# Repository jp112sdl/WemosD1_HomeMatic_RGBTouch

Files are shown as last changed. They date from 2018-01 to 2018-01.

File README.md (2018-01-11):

# WemosD1 HomeMatic RGBTouch Controller
TFT/Touchscreen-Fernbedienung für HomeMatic RGB Controller und/oder UP-Dimmer<br>
Die Steuerung erfolgt direkt über die Seriennummer des HomeMatic-Geräts.<br>
Es ist **keine** Zusatzsoftware auf der CCU2 notwendig.

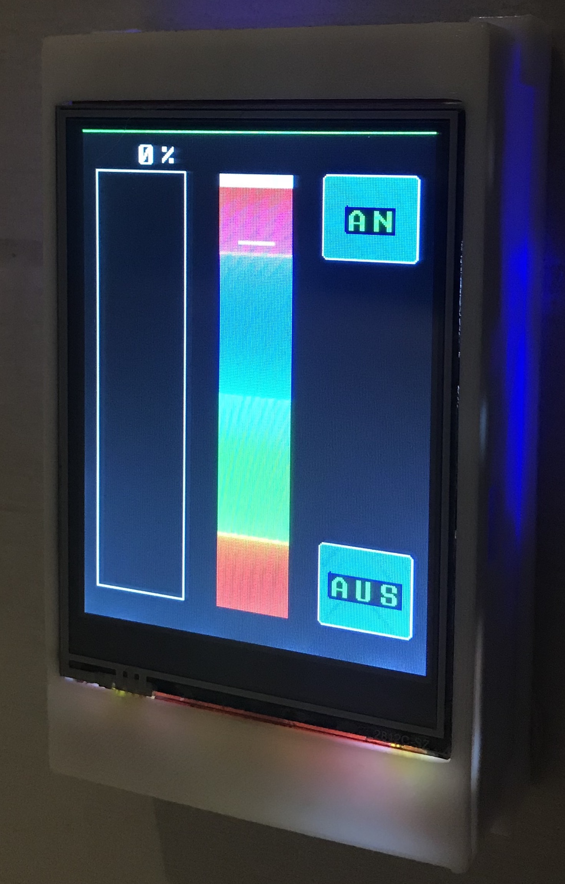
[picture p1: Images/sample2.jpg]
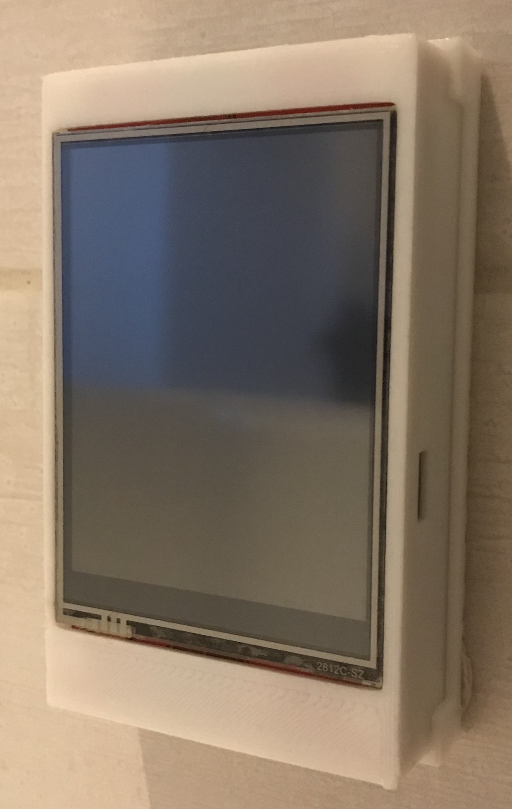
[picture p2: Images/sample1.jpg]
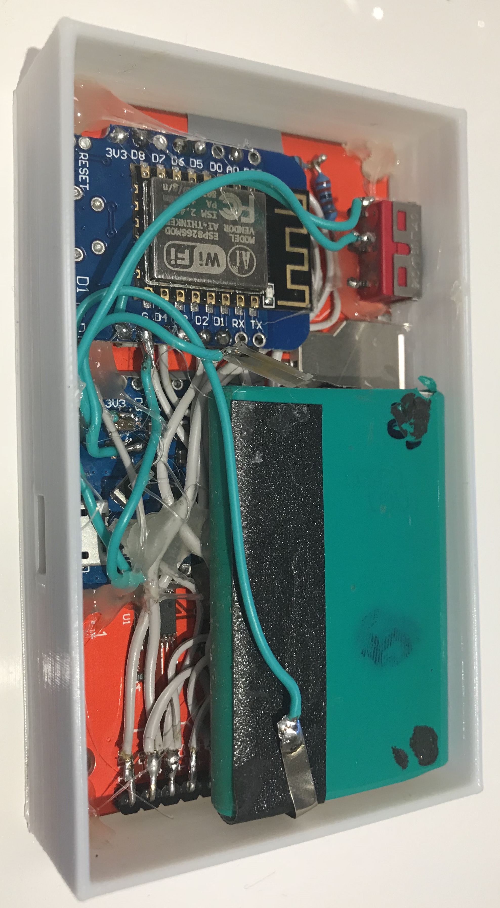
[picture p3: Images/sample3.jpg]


### Bauteile:
- 1x Wemos D1 mini
- 1x TFT Touchscreen, ILI9341 kompatibel und mit SPI Anschluss (z.B. [hier](https://www.ebay.de/itm/172726994916))
- 1x beliebiger Taster
- 1x Widerstand, irgendwas zwischen 1k...10k Ohm (dient nur als Pullup)
- _bei Akkubetrieb empfiehlt sich zusätzlich noch ein Wemos BatteryShield und ein 3.7V LiPo Akku_
  - _auf die Stromversorgung wird hier nicht weiter eingegangen_
  
### Verdrahtung:
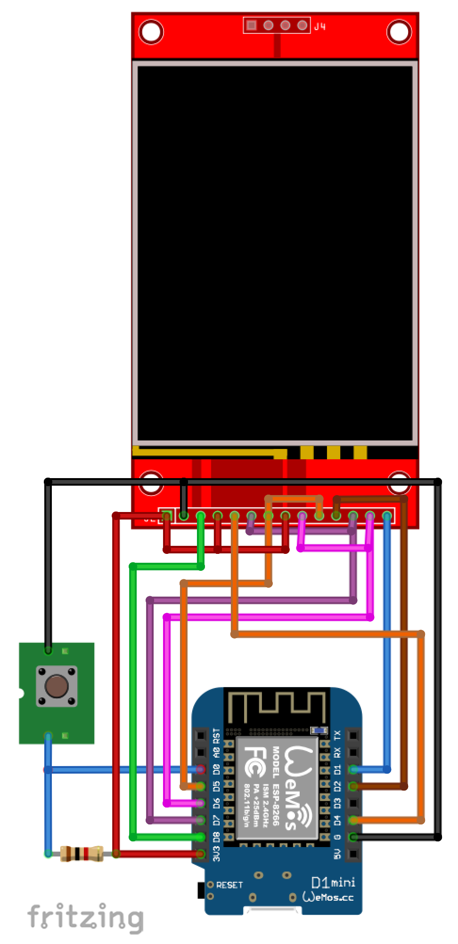
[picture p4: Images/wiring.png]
<br>
Die Fritzing-Datei kann auch [heruntergeladen](https://github.com/jp112sdl/WemosD1_HomeMatic_RGBTouch/blob/master/Images/Schaltplan.fzz) werden.

### Inbetriebnahme:
1. Touchscreen berühren und dabei das Gerät einschalten
2. AP-Modus wird gestartet<br>
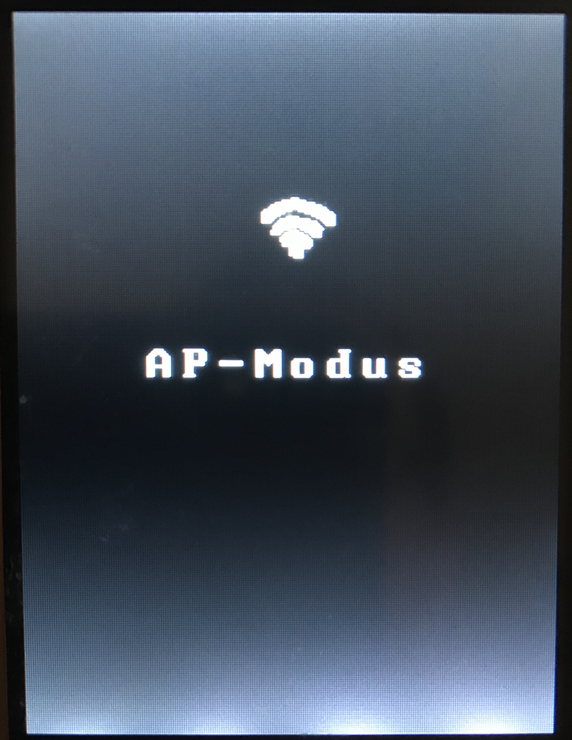
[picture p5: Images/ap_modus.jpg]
<br>
3. Nach neuen WLANs am Notebook suchen und mit dem WLAN WemosD1-xx:xx:xx:xx:xx:xx verbinden
4. Konfigurationsseite öffnen: http://192.168.4.1 und dort die Daten entsprechend eingeben, anschließend speichern.

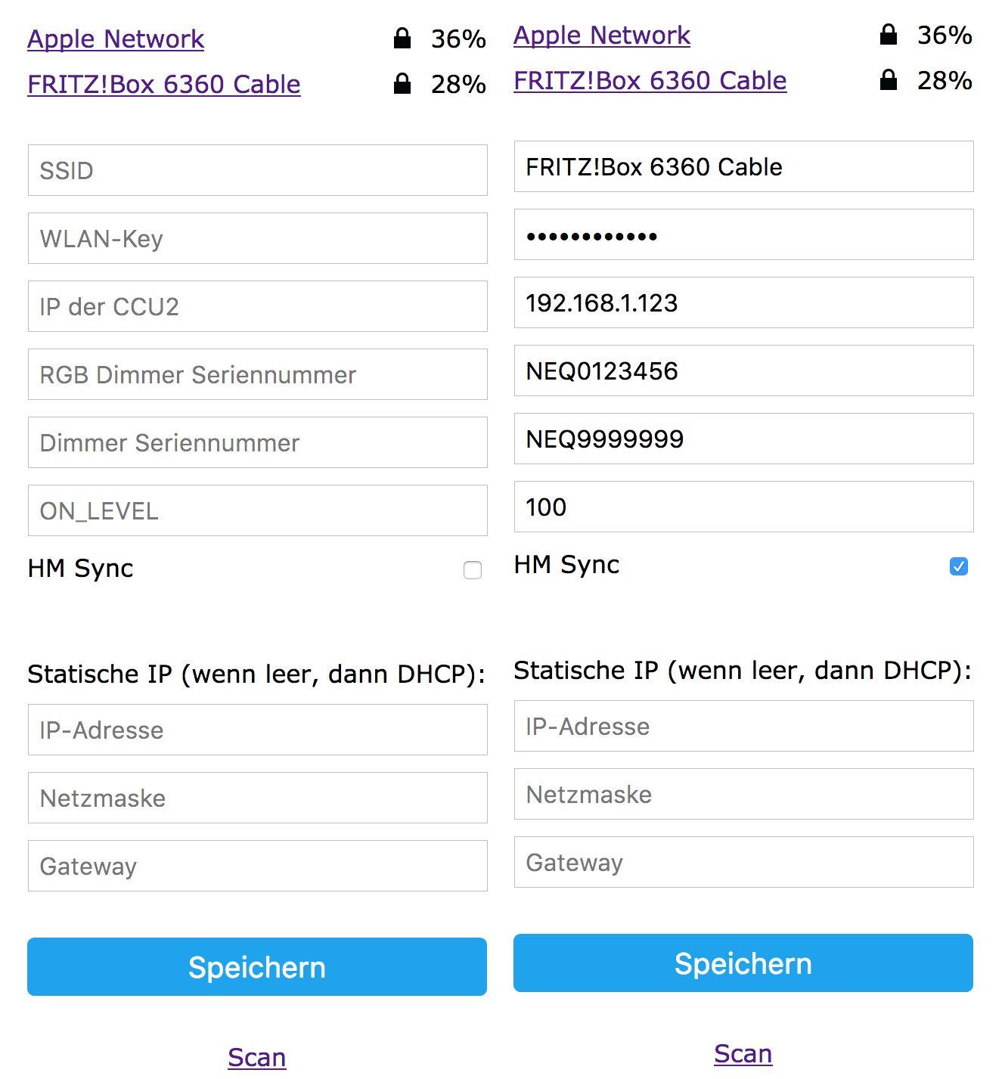
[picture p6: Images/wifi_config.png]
<br>

**Erklärung der Felder:**
- SSID / WLAN-Key, IP der CCU2, RGB Dimmer Seriennummer und UP Dimmer Seriennummer sind wohl selbsterklärend
- **es ist auch möglich nur EINEN von beiden Dimmern zu benutzen! Es ist dann das Feld (Seriennummer) des ungenutzten Dimmertyps leer zu lassen.**
- ON_LEVEL: Die Buttons AN und AUS am rechten Bildschirmrand dienen dem schnellen Ein- und Ausschalten des UP-Dimmers. Bei "AUS" wird 0% angefahren, bei "EIN" der im ON_LEVEL definierte Wert.
- HM Sync: wenn aktiviert, wird alle 30 Sekunden die CCU2 abgefragt, ob die angezeigten Werte noch dem IST-Zustand entsprechen. Wenn nicht (weil bspw. jemand per Schalter den Dimmer betätigt hat) wird der neue/aktuelle Wert am TFT angezeigt.

### Gehäuse:
Mein verwendetes Gehäuse gibt es als [.stl](https://github.com/jp112sdl/WemosD1_HomeMatic_RGBTouch/blob/master/Images/HomeMatic%20RGB%20Dimmer.stl) und als [.obj](https://github.com/jp112sdl/WemosD1_HomeMatic_RGBTouch/blob/master/Images/HomeMaticRGBDimmerOBJ.zip) im komprimierten zip-File.

### Kalibrierung des Touchscreens:
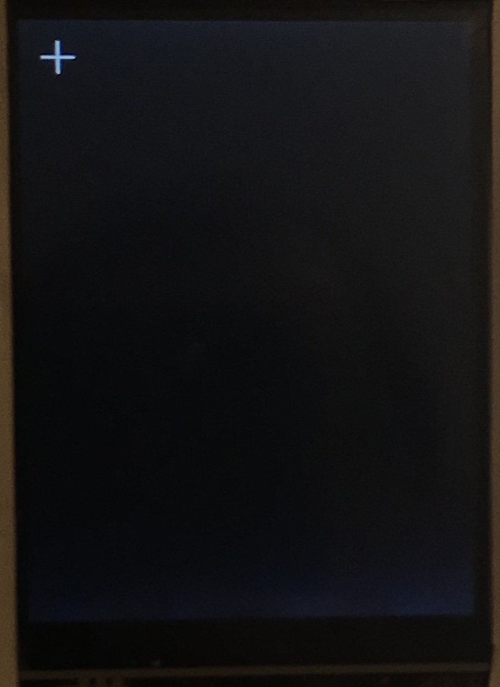
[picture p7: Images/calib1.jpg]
<br>
- Bei gedrücktem Taster den Wemos einschalten.<br>
- Es erscheint ein Fadenkreuz in der Ecke oben links
- Das Fadenkreuz (am besten mit einem Stift) antippen
- Es erscheint ein Fadenkreuz in der Ecke unten rechts
- Das Fadenkreuz (am besten mit einem Stift) antippen

Die Kalibrierung ist nun beendet. Die Kalibrierungsdaten werden gespeichert und sind dauerhaft gespeichert.
Der Vorgang kann jederzeit wiederholt werden

Wer "Danke" sagen möchte (in Form einer kleinen Spende), kann gern hier klicken:

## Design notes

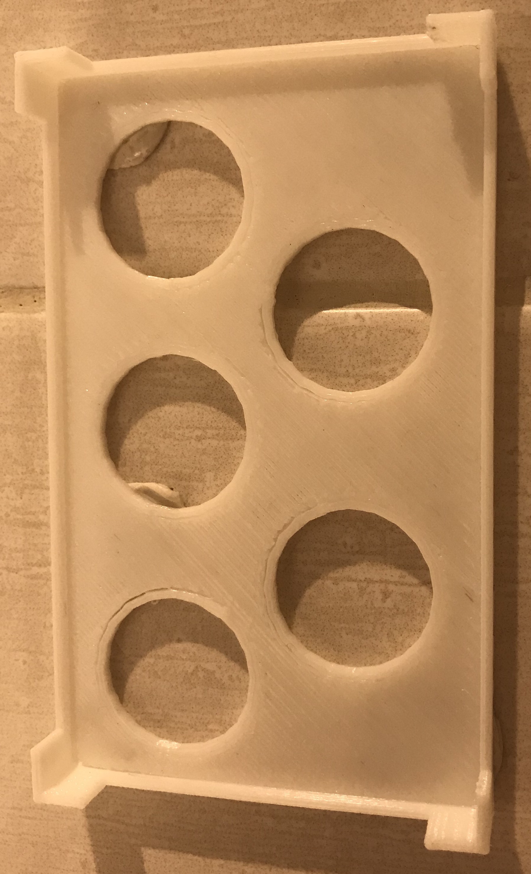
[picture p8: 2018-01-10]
Images/sample4.jpg

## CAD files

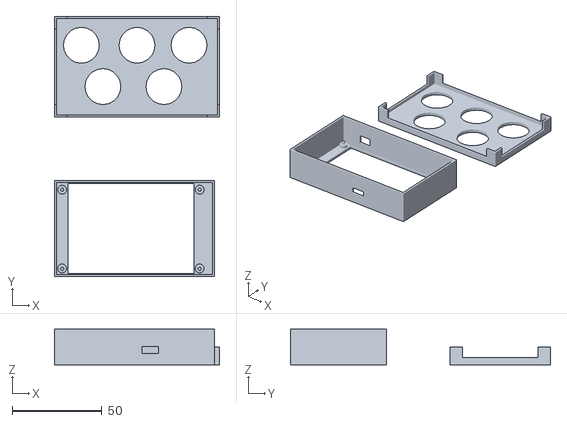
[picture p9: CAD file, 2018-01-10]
Images/HomeMatic RGB Dimmer.stl
92.2 x 145.2 x 20.0

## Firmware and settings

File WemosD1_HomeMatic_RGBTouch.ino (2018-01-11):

#include <ESP8266WiFi.h>
#include <ESP8266HTTPClient.h>
#include <Arduino.h>
#include <FS.h>
#include <ArduinoOTA.h>
#include <UTFT.h>
#include <SPI.h>
#include <XPT2046.h>
#include <ArduinoJson.h>
#include <WiFiManager.h>

#define ESP_SPI_FREQ 16000000L

#define IPSIZE                16
#define VARIABLESIZE         255
#define ConfigPortalTimeout  180  //Timeout (Sekunden) des AP-Modus
#define HTTPTimeOut         1500  //Timeout (Millisekunden) für http requests
#define SYNCINTERVAL         30   //Sekunden
#define CalibrationSwitch    D0   //Taster zum Starten der Touchscreen-Kalibrierung

const String configJsonFile         = "tc.json";
const String calibJsonFile          = "cal.json";

extern unsigned  wifiicon32[1024];
extern unsigned  RGBhorz_halb[27948];

UTFT myGLCD (ILI9341_S5P, 15, 5, 2);
XPT2046 myTouch(/*cs=*/ 4, /*irq=*/ 5);

HTTPClient http;

char Hostname[] = "WEMOS-HM-RGBTOUCH";

struct wemosnetconfig_t {
  char ip[IPSIZE]      = "0.0.0.0";
  char netmask[IPSIZE] = "0.0.0.0";
  char gw[IPSIZE]      = "0.0.0.0";
} WemosNetConfig;

struct hmconfig_t {
  char ccuIP[IPSIZE]   = "";
  char RGB_Dimmer_Serial[VARIABLESIZE] = "";
  char UP_Dimmer_Serial[VARIABLESIZE] =  "";
  bool enableSync = false;
  byte OnLevel = 100;
} HomeMaticConfig;

struct touchcalibration_t {
  int P1 = 244;
  int P2 = 1735;
  int P3 = 1728;
  int P4 = 264;
} TouchCalibration;

bool isDimTouching = false;
bool isRGBTouching = false;
int posX = 20; // Start x
int posY = 10; // Start y
int posEndX = 274;
int posEndY = 65;
int percentX = 312;
int percentY = 8;

int buttonWidth = 50;
int buttonHeight = 60;
int buttonOffX = 20;
int buttonOffY = 170;
int buttonOnX = 244;
int buttonOnY = 170;

int wifiIconX = 210;
int wifiIconY = 108;
int RGBstartX = 20;
int RGBstartY = 100;
int RGBheight = 274;
int RGBwidth = 25;
int RGBbarCount = 2;

boolean isFrameSet = false; // Wert wird true wenn Frame erstmalig geschrieben - nicht manuell anpassen!
extern uint8_t BigFont[];
int intAusgabe;
unsigned long lastSyncMillis = 0;

//bool Debug = false;
bool startWifiManager = false;
bool wm_shouldSaveConfig = false;
bool isRGBavailable = true;
bool isDIMavailable = true;
String lastLEVELValue = "";
String lastCOLORValue = "";


void setup() {
  pinMode(LED_BUILTIN, OUTPUT);
  pinMode(CalibrationSwitch, INPUT);
  SPI.setFrequency(ESP_SPI_FREQ);
  myGLCD.InitLCD(LANDSCAPE);
  myGLCD.clrScr();
  myGLCD.setFont(BigFont);
  myGLCD.setColor(255, 255, 255);
  Serial.begin(115200);

  myTouch.begin((uint16_t)myGLCD.getDisplayYSize(), (uint16_t)myGLCD.getDisplayXSize());

  if (digitalRead(CalibrationSwitch) == LOW) {
    calibrate();
  } else {
    loadCalibrationConfig();
  }
  
  myTouch.setRotation(myTouch.ROT270);
  myTouch.setCalibration(TouchCalibration.P1, TouchCalibration.P2, TouchCalibration.P3, TouchCalibration.P4);

  if (!loadSystemConfig()) startWifiManager = true;
  if (myTouch.isTouching()) startWifiManager = true;

  isRGBavailable = (String(HomeMaticConfig.RGB_Dimmer_Serial) != "");
  isDIMavailable = (String(HomeMaticConfig.UP_Dimmer_Serial) != "");

  if (doWifiConnect() == false) {
    myGLCD.clrScr();
    myGLCD.setFont(BigFont);
    myGLCD.setColor(255, 255, 255);
    myGLCD.print("  Fehler bei ", 175, 00, 90);
    myGLCD.print("WLAN-Verbindung", 155, 00, 90);
    delay(2000);
    ESP.restart();
  }
  else {
    startOTAhandling();
    myGLCD.clrScr();
    slider_init();
    if (isDIMavailable) on_off_button_init();
  }
}

void loop() {
  ArduinoOTA.handle();
  if (lastSyncMillis > millis())
    lastSyncMillis = millis();

  if (WiFi.status() == WL_CONNECTED) {
    slider_read();
    if (millis() - lastSyncMillis > SYNCINTERVAL * 1000) {
      Serial.println("SYNC HM");
      lastSyncMillis = millis();
      slider_init();
    }

    yield();

  } else ESP.restart();
}

void slider_init() {
  myGLCD.setColor(255, 255, 255);
  myGLCD.drawRect (posX, posY, posX + posEndX, posY + posEndY);
  bool CCUerror = false;
  if (!isRGBavailable) {
    memcpy(HomeMaticConfig.RGB_Dimmer_Serial, HomeMaticConfig.UP_Dimmer_Serial, VARIABLESIZE);
    Serial.println("slider_init(): RGB Dimmer NOT available");
  }
  //aktuellen LEVEL holen und anzeigen
  String currentLEVELValue = getStateFromCCU(HomeMaticConfig.RGB_Dimmer_Serial, "1.LEVEL");
  if (currentLEVELValue != lastLEVELValue) {
    lastLEVELValue = currentLEVELValue;
    CCUerror = !drawCurrentDimLevel(currentLEVELValue);
  }

  if (isRGBavailable) {
    String currentCOLORValue = getStateFromCCU(HomeMaticConfig.RGB_Dimmer_Serial, "2.COLOR");
    if (currentCOLORValue != "error") {
      if (currentCOLORValue != lastCOLORValue) {
        lastCOLORValue = currentCOLORValue;
        myGLCD.setColor(255, 255, 255);

        int knobPosX = (((float)currentCOLORValue.toInt() / 200.0) + ((float)RGBstartX / (float)RGBheight)) * (float)RGBheight;
        draw_knob(knobPosX);
        yield();
      }
    } else {
      CCUerror = true;
    }
  }

  if (CCUerror) {
    myGLCD.clrScr();
    myGLCD.setFont(BigFont);
    myGLCD.setColor(255, 255, 255);
    myGLCD.print("  Fehler bei ", 175, 00, 90);
    myGLCD.print("CCU2-Verbindung", 155, 00, 90);
    myGLCD.setColor(255, 0, 0);
    myGLCD.drawLine(319, 0, 319, 240);
    myTouch.powerDown();
  } else {
    myGLCD.setColor(0, 255, 0);
    myGLCD.drawLine(319, 0, 319, 240);
  }
}

void on_off_button_init() {
  //AN / AUS BUTTONS
  myGLCD.setColor(0, 0, 255);
  myGLCD.fillRoundRect (buttonOffX, buttonOffY, buttonOffX + buttonWidth, buttonOffY + buttonHeight);
  myGLCD.setColor(255, 255, 255);
  myGLCD.drawRoundRect (buttonOffX, buttonOffY, buttonOffX + buttonWidth, buttonOffY + buttonHeight);

  myGLCD.setColor(0, 0, 255);
  myGLCD.fillRoundRect (buttonOnX, buttonOnY, buttonOnX + buttonWidth, buttonOnY + buttonHeight);
  myGLCD.setColor(255, 255, 255);
  myGLCD.drawRoundRect (buttonOnX, buttonOnY, buttonOnX + buttonWidth, buttonOnY + buttonHeight);

  myGLCD.setColor(0, 255, 0);
  myGLCD.print("AUS",   52, 177, 90);
  myGLCD.print("AN",   275, 185, 90);
  //
}

// Slider auslesen und Werte zurückgeben
int slider_read() {
  float tPosX;
  float tPosY;
  float tAusgabe;
  if (myTouch.isTouching()) {
    //Serial.println("Touch detected.");
    uint16_t x, y;
    int xCumul = 0;
    int yCumul = 0;
    for (int touchCount = 0; touchCount < 100; touchCount++) {
      myTouch.getPosition(x, y);
      xCumul += x;
      yCumul += y;
    }
    tPosX = xCumul / 100;
    tPosY = yCumul / 100;
    //Serial.println("tPosX = " + String(tPosX) + "; tPosY = " + String(tPosY));

    if (isDIMavailable) {
      if ((tPosY > buttonOffY) && (tPosY < buttonOffY + buttonHeight)) {
        if ((tPosX > buttonOffX) && (tPosX < buttonOffX + buttonWidth)) {
          waitForIt(buttonOffX, buttonOffY, buttonOffX + buttonWidth, buttonOffY + buttonHeight);
          Serial.println("OFF BUTTON pressed.");
          setStateCCU(HomeMaticConfig.UP_Dimmer_Serial, "1.LEVEL", "0.0");
          if (!isRGBavailable) drawCurrentDimLevel("0");
        }
      }

      if ((tPosY > buttonOnY) && (tPosY < buttonOnY + buttonHeight)) {
        if ((tPosX > buttonOnX) && (tPosX < buttonOnX + buttonWidth)) {
          waitForIt(buttonOnX, buttonOnY, buttonOnX + buttonWidth, buttonOnY + buttonHeight);
          Serial.println("ON BUTTON pressed. ON_LEVEL = " + String(HomeMaticConfig.OnLevel));
          setStateCCU(HomeMaticConfig.UP_Dimmer_Serial, "1.LEVEL", String((float)(HomeMaticConfig.OnLevel / 100.0)));
          if (!isRGBavailable) drawCurrentDimLevel(String((float)(HomeMaticConfig.OnLevel / 100.0)));
        }
      }
    }

    if (tPosX >= posX && tPosX <= posX + posEndX && tPosY >= posY && tPosY <= posY + posEndY) {
      isDimTouching = true;
      draw_used_unused(tPosX, tPosY);
      tAusgabe = ((tPosX - posY) / posEndX) * 100;
      intAusgabe = (int)tAusgabe - 3;
      String displayPercent = "   " + String(intAusgabe);
      displayPercent = displayPercent.substring(displayPercent.length() - 3) + "%";
      myGLCD.setColor(255, 255, 255);
      myGLCD.print(displayPercent, percentX, percentY, 90);
    }
    //RGB
    if (isRGBavailable && tPosX >= RGBstartX && tPosX <= RGBstartX + RGBheight && tPosY >= RGBstartY && tPosY <= RGBstartY +  (RGBwidth * RGBbarCount)) {
      draw_knob(tPosX);
      isRGBTouching = true;
      tAusgabe = ((tPosX - RGBstartX) / RGBheight) * 200;
      intAusgabe = (int) tAusgabe;
    }
  }
  else {
    if (isDimTouching) {
      if (intAusgabe < 4) intAusgabe = 0;
      String val = "00" + String(intAusgabe);
      val = "0." + val.substring(val.length() - 2);
      Serial.println("Setze CCU Wert " + String(HomeMaticConfig.RGB_Dimmer_Serial) + "1.LEVEL = " + val);
      setStateCCU(HomeMaticConfig.RGB_Dimmer_Serial, "1.LEVEL", val);
      isDimTouching = false;
    }
    //RGB
    if (isRGBTouching) {
      Serial.println("Setze CCU Wert " + String(HomeMaticConfig.RGB_Dimmer_Serial) + "2.COLOR = " + String(intAusgabe));
      setStateCCU(HomeMaticConfig.RGB_Dimmer_Serial, "2.COLOR", String(intAusgabe));
      isRGBTouching = false;
    }
  }
}

// Draw a red frame while a button is touched
void waitForIt(int x1, int y1, int x2, int y2) {
  myGLCD.setColor(255, 0, 0);
  myGLCD.drawRoundRect (x1, y1, x2, y2);
  while (myTouch.isTouching()) yield(); //loop
  myGLCD.setColor(255, 255, 255);
  myGLCD.drawRoundRect (x1, y1, x2, y2);
}

// Schieberegler
void draw_knob(int tPosX) {
  word tColor;
  for (int barCount = 0; barCount < RGBbarCount; barCount++)
    myGLCD.drawBitmap (RGBstartX, RGBstartY + (RGBwidth * barCount), RGBheight, RGBwidth, RGBhorz_halb, 1);
  tColor = myGLCD.getColor();
  myGLCD.setColor(255, 255, 255);

  myGLCD.fillRect(tPosX - 1, RGBstartY + ( (RGBwidth * RGBbarCount) / 2) - ( (RGBwidth * RGBbarCount) / 4), tPosX, RGBstartY + ( (RGBwidth * RGBbarCount) / 2) + ( (RGBwidth * RGBbarCount) / 4));
  // myGLCD.drawLine(posX, RGBstartY + ( (RGBwidth * RGBbarCount) / 2), tPosX, RGBstartY + ( (RGBwidth * RGBbarCount) / 2));

  myGLCD.setColor(tColor);
}

void draw_used_unused(int tPosX, int tPosY) {
  //Serial.println("draw_used_unused("+String(tPosX)+","+String(tPosY)+")");
  const word usedColor = VGA_WHITE; // Farbe f. genutzen Anteil
  const word unusedColor = VGA_BLACK; // Farbe f. ungenutzen Anteil
  word tColor;
  tColor = myGLCD.getColor();
  myGLCD.setColor(usedColor);
  for (int tPosY = posY; tPosY <= posY + posEndY; tPosY++) myGLCD.drawLine(posX, tPosY, tPosX, tPosY);
  myGLCD.setColor(tColor);
  myGLCD.setColor(unusedColor);
  for (int tPosY = posY; tPosY <= posY + posEndY; tPosY++) myGLCD.drawLine(tPosX, tPosY, posX + posEndX, tPosY);
  myGLCD.setColor(255, 255, 255);
  myGLCD.drawRect (posX, posY, posX + posEndX, posY + posEndY);
  myGLCD.setColor(tColor);
}

String IpAddress2String(const IPAddress& ipAddress) {
  return String(ipAddress[0]) + String(".") + \
         String(ipAddress[1]) + String(".") + \
         String(ipAddress[2]) + String(".") + \
         String(ipAddress[3]);
}

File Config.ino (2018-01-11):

#define JSONCONFIG_IP                     "ip"
#define JSONCONFIG_NETMASK                "netmask"
#define JSONCONFIG_GW                     "gw"
#define JSONCONFIG_CCUIP                  "ccuip"
#define JSONCONFIG_RGBDIMMER              "rgbdimser"
#define JSONCONFIG_UPDIMMER               "updimmer"
#define JSONCONFIG_ENABLESYNC             "sync"
#define JSONCONFIG_ONLEVEL                "onlevel"

bool loadSystemConfig() {
  Serial.println(F("loadSystemConfig mounting FS..."));
  if (SPIFFS.begin()) {
    Serial.println(F("loadSystemConfig mounted file system"));
    if (SPIFFS.exists("/" + configJsonFile)) {
      Serial.println(F("loadSystemConfig reading config file"));
      File configFile = SPIFFS.open("/" + configJsonFile, "r");
      if (configFile) {
        Serial.println(F("loadSystemConfig opened config file"));
        size_t size = configFile.size();
        std::unique_ptr<char[]> buf(new char[size]);

        configFile.readBytes(buf.get(), size);
        DynamicJsonBuffer jsonBuffer;
        JsonObject& json = jsonBuffer.parseObject(buf.get());
        Serial.println("Content of JSON Config-File: /" + configJsonFile);
        json.printTo(Serial);
        Serial.println();
        if (json.success()) {
          Serial.println("\nJSON OK");
          ((json[JSONCONFIG_IP]).as<String>()).toCharArray(WemosNetConfig.ip, IPSIZE);
          ((json[JSONCONFIG_NETMASK]).as<String>()).toCharArray(WemosNetConfig.netmask, IPSIZE);
          ((json[JSONCONFIG_GW]).as<String>()).toCharArray(WemosNetConfig.gw, IPSIZE);
          ((json[JSONCONFIG_CCUIP]).as<String>()).toCharArray(HomeMaticConfig.ccuIP, IPSIZE);
          ((json[JSONCONFIG_RGBDIMMER]).as<String>()).toCharArray(HomeMaticConfig.RGB_Dimmer_Serial, VARIABLESIZE);
          ((json[JSONCONFIG_UPDIMMER]).as<String>()).toCharArray(HomeMaticConfig.UP_Dimmer_Serial, VARIABLESIZE);
          HomeMaticConfig.enableSync = json[JSONCONFIG_ENABLESYNC];
          HomeMaticConfig.OnLevel = json[JSONCONFIG_ONLEVEL];
        } else {
          Serial.println(F("\nloadSystemConfig ERROR loading config"));
        }
      }
      return true;
    } else {
      Serial.println("/" + configJsonFile + " not found.");
      return false;
    }
    SPIFFS.end();
  } else {
    Serial.println(F("loadSystemConfig failed to mount FS"));
    return false;
  }
}

bool saveSystemConfig() {
  SPIFFS.begin();
  Serial.println(F("saving system config"));
  DynamicJsonBuffer jsonBuffer;
  JsonObject& json = jsonBuffer.createObject();
  json[JSONCONFIG_IP] = WemosNetConfig.ip;
  json[JSONCONFIG_NETMASK] = WemosNetConfig.netmask;
  json[JSONCONFIG_GW] = WemosNetConfig.gw;
  json[JSONCONFIG_CCUIP] = HomeMaticConfig.ccuIP;
  json[JSONCONFIG_RGBDIMMER] = HomeMaticConfig.RGB_Dimmer_Serial;
  json[JSONCONFIG_UPDIMMER] = HomeMaticConfig.UP_Dimmer_Serial;
  json[JSONCONFIG_ENABLESYNC] = HomeMaticConfig.enableSync;
  json[JSONCONFIG_ONLEVEL] = HomeMaticConfig.OnLevel;

  SPIFFS.remove("/" + configJsonFile);
  File configFile = SPIFFS.open("/" + configJsonFile, "w");
  if (!configFile) {
    Serial.println(F("failed to open config file for writing"));
    return false;
  }
  json.printTo(Serial);
  Serial.println();
  json.printTo(configFile);
  configFile.close();
  SPIFFS.end();
  return true;
}

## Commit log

2018-01-10 added images
    [HomeMatic RGB Dimmer.stl, Schaltplan.fzz]
2018-01-10 added calibration routines
2018-01-10 prep for calibration
2018-01-10 disabled calibration
2018-01-11 changed images
    [Schaltplan.fzz]
2018-01-11 extended calibration methods
2018-01-11 added touch screen calibration
